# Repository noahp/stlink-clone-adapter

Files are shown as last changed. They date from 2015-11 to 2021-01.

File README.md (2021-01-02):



# stlink-clone-adapter <!-- omit in toc -->

- [Variants](#variants)
  - [Variant 1](#variant-1)
  - [Variant 2](#variant-2)
  - [Variant X](#variant-x)
- [PCB Renders](#pcb-renders)
  - [Variant-1](#variant-1-1)
  - [Variant-2](#variant-2-1)
- [Part list](#part-list)
- [pyocd](#pyocd)

Adapter board for a 2x5 0.1" (2.54mm) header to arm cortex 10-pin connector.

This is useful when connecting ST-Link v2 clones to a standard ARM 2x5 1.27mm
pitch header.

## Variants

I know of 2 variants of the ST-Link v2 clones, with different pinouts on the 2x5 0.1"
(2.54mm) header. Different adapter boards provided for each variant.

One way to distinguish the variants; when unplugged, check for continuity on pins 3+4 or 5+6.

- pins 3+4 shorted, **variant-1**
- pins 5+6 shorted, **variant-2**

### Variant 1

Older model I bought in ~2016.

From the pin 1 marker on the header on the ST-Link, pinout is as follows:

|Funtion|Pin|Pin|Function|
|---|---|---|---|
|RST*|1|2|SWDIO|
|GND*|3|4|GND|
|SWIM|5|6|SWCLK|
|3.3V|7|8|3.3V|
|5.0V|9|10|5.0V|

**Note that the labeling is incorrect for some pins on the etching on the case /
on the silkscreen on the board. My device had the pinout for **Variant-2** on
the etching and just incorrect on the silkscreen markings 🤷.*

### Variant 2

Newer model I bought in 2020.

From the pin 1 marker on the header on the ST-Link, pinout is as follows:

|Funtion|Pin|Pin|Function|
|---|---|---|---|
|RST|1|2|SWCLK|
|SWIW|3|4|SWDIO|
|GND|5|6|GND|
|3.3V|7|8|3.3V|
|5.0V|9|10|5.0V|

Labeling appears to be correct on these devices.

### Variant X

*UNTESTED DESIGN*

Support both pinouts with a 3x4 0.1" header to select between them.

Alternative approaches:

- digital selection (mux the 4 connectors), controlled somehow by the signals.
  this has the defect of additional propogation losses through the mux, and
  complexity in the control circuit
- provide 2 2x5 0.1" headers on the board (would be a funky looking board!). the
  connectors are somewhat expensive at $0.80 @ qty 1 but makes for a simpler
  design
- provide a single 6-pin strip (3.3v, GND, RST, SWDIO, SWCLK, SWO) and use 0.1"
  jumper connectors to wire it to the probe (kinda janky connection vs. single
  connector though).

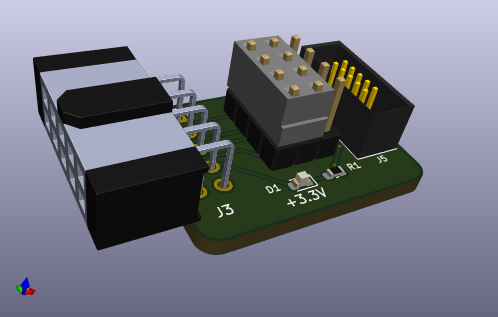
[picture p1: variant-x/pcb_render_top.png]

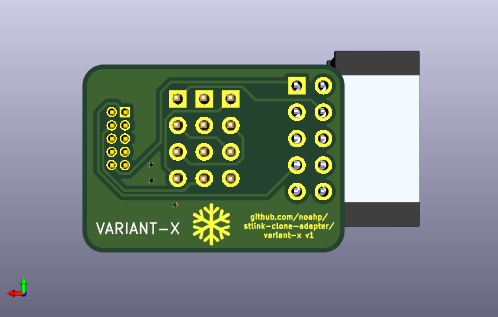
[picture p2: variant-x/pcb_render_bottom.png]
bottom


## PCB Renders

### Variant-1

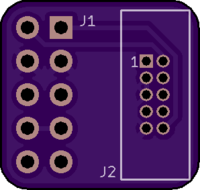
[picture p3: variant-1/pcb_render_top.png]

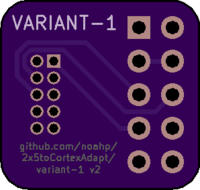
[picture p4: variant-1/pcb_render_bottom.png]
bottom


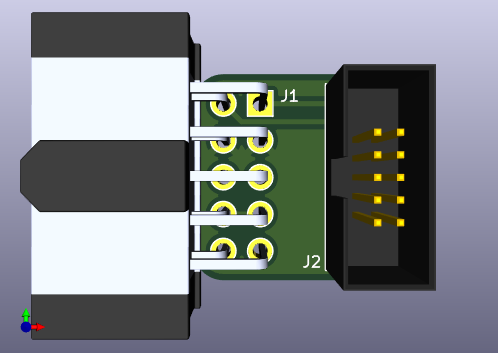
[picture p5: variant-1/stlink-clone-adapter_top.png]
3d-top

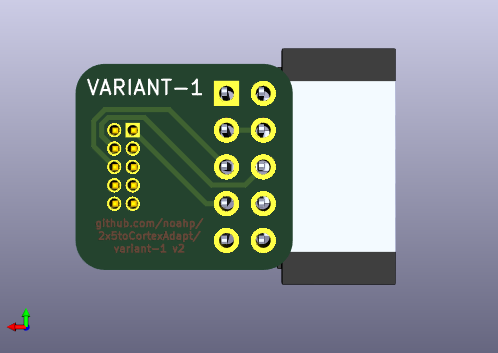
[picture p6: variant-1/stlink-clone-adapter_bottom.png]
3d-bottom


### Variant-2

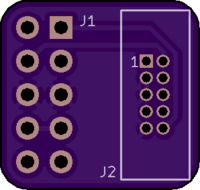
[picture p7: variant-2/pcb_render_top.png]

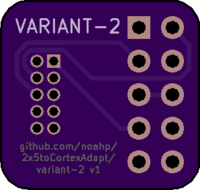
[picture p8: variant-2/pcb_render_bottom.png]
bottom


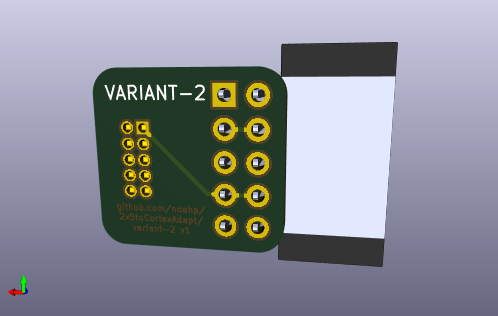
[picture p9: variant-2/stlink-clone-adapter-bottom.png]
3d


## Part list

- [2x5 header](http://www.digikey.com/product-search/en?keywords=SFH11-PBPC-D05-RA-BK)
- [arm 10 pin](http://www.digikey.com/product-detail/en/3220-10-0100-00/1175-1627-ND/3883661)
- [2x4 shunt/jumper](https://www.digikey.com/en/products/detail/amphenol-icc-fci/69145-208LF/1523748) [alternate](https://www.digikey.com/en/products/detail/samtec-inc/MNT-104-BK-G/6613574)

## pyocd

Quick note about using the stlink v2 clones with pyocd; I had the best luck
using the device after updating the firmware using the [official ST
updater](https://www.st.com/en/development-tools/stsw-link007.html):

```bash
❯ java -jar stsw-link007/AllPlatforms/STLinkUpgrade.jar -jtag_swim -force_prog
Firmware version detected: V2J29S7
................Upgrade is successful.
Version read: 2.37.7
```

After upating the version should report `V2J37S7` if you run the updater again.

There's a ton of information out there on the stlink devices themselves (I found
[this](https://hackaday.io/project/162597-st-link-clone-repurposing) helpful).

On ubuntu there's an available package
[stlink-tools](https://packages.ubuntu.com/search?keywords=stlink-tools)
([source](https://github.com/stlink-org/stlink)) which contains some utilities and udev rules for the st-link devices. I didn't end up using the tools themselves
but it could come in handy.

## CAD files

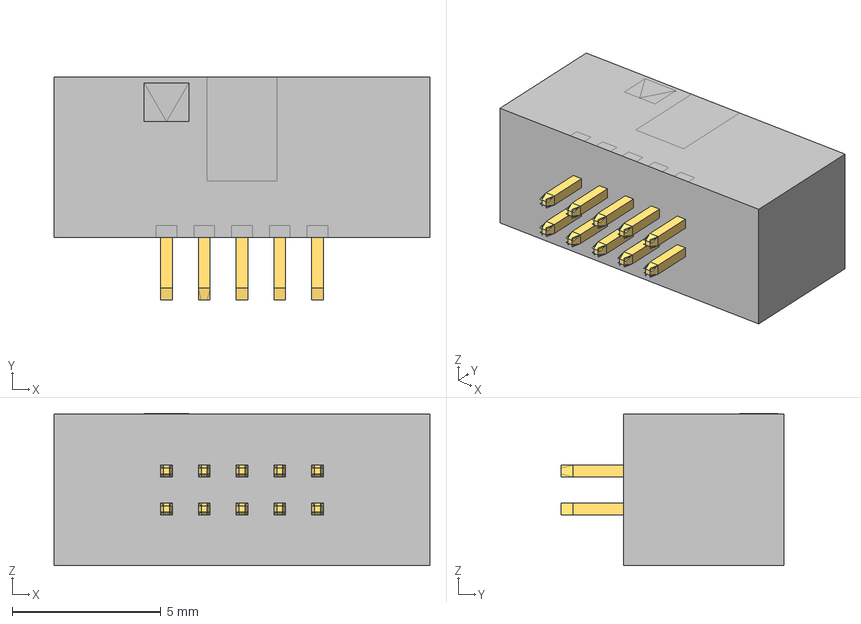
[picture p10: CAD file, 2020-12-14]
3220-10-0100.igs
12.7 x 7.50 x 5.13 mm

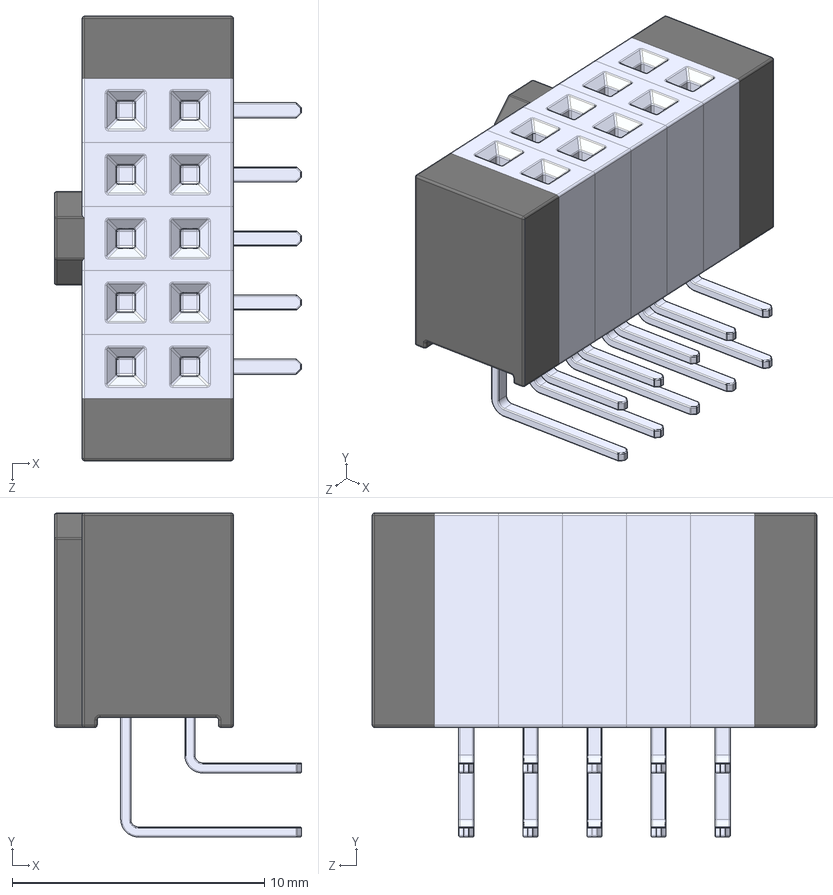
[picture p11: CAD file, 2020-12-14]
SFH11-xxPC-D05-RA-BK.IGS
9.80 x 12.8 x 17.6 mm

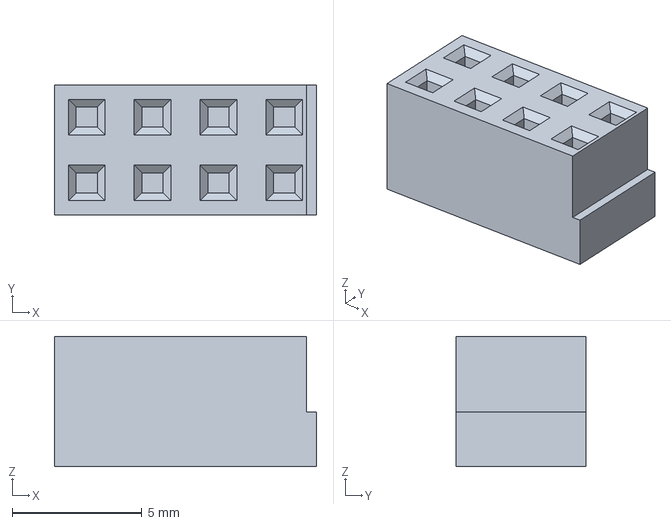
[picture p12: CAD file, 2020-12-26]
69145-x08.igs
10.1 x 5.03 x 5.03 mm

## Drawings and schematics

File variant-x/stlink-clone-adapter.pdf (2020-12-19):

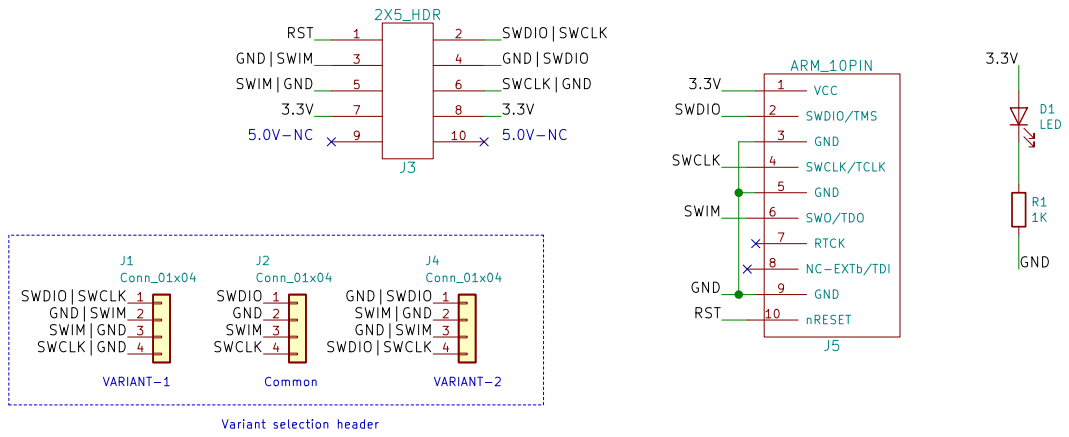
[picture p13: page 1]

File: stlink-clone-adapter.sch Sheet: /
Id: 1/1 Title:

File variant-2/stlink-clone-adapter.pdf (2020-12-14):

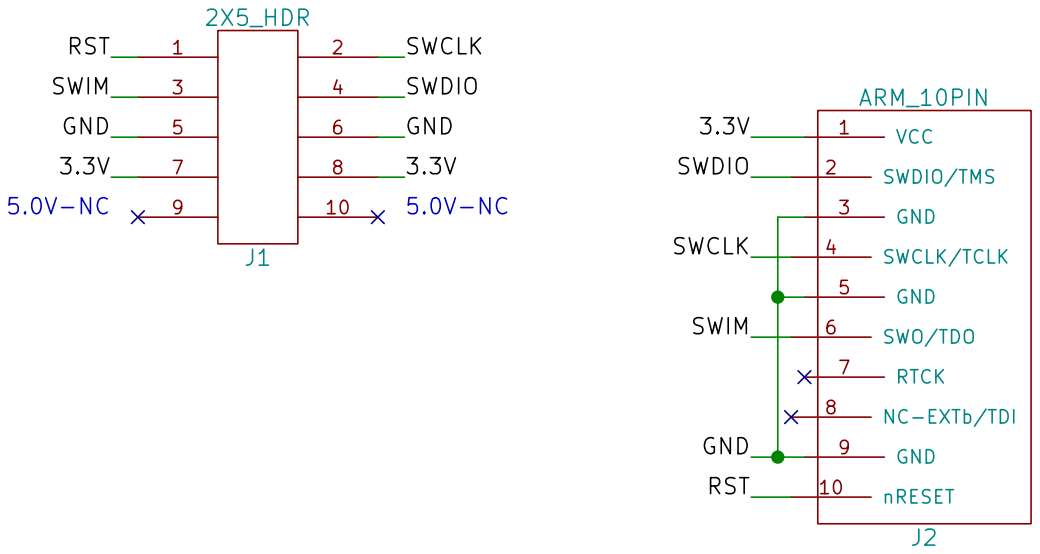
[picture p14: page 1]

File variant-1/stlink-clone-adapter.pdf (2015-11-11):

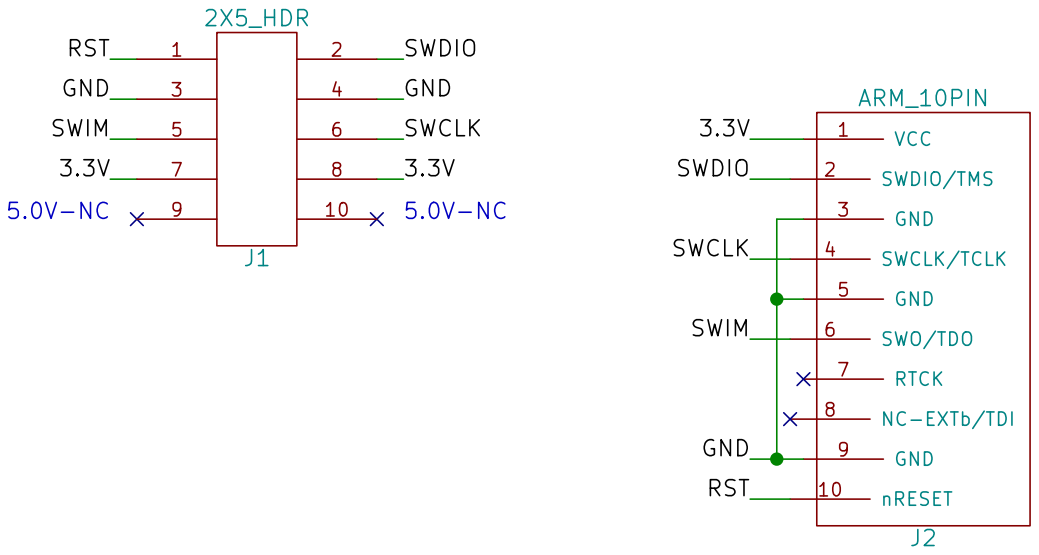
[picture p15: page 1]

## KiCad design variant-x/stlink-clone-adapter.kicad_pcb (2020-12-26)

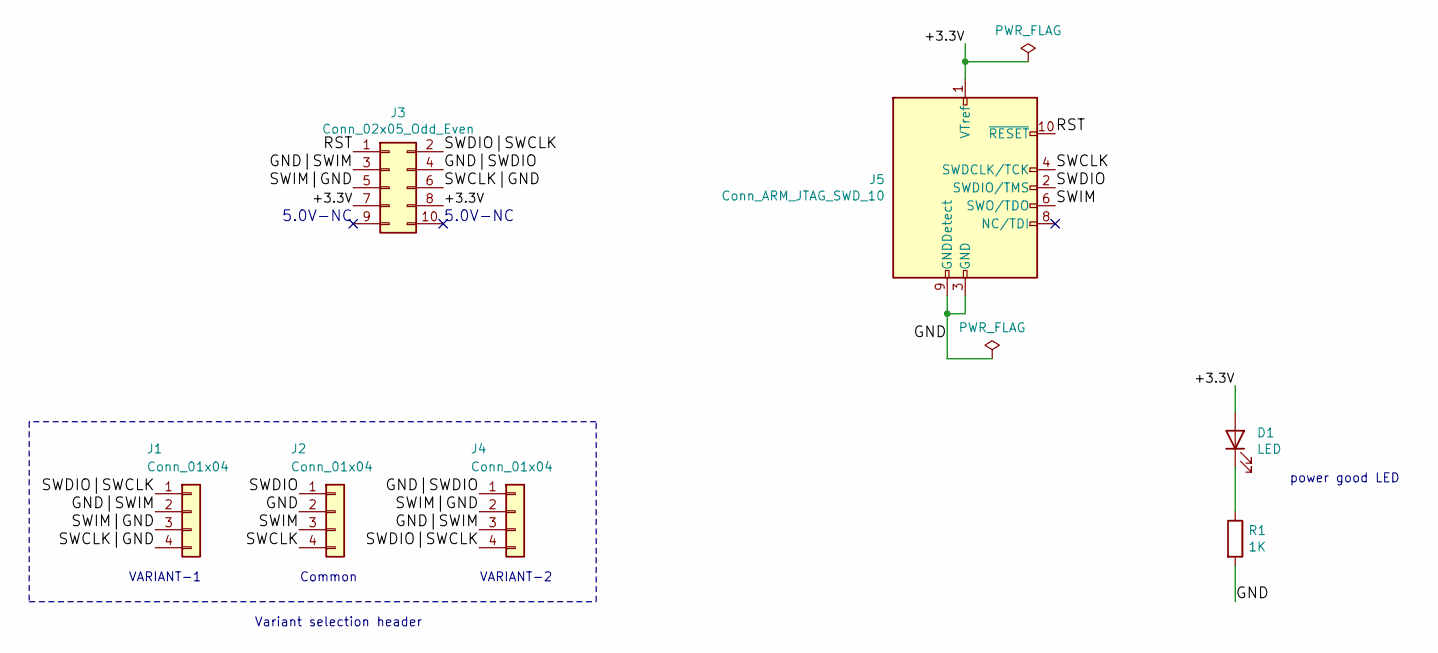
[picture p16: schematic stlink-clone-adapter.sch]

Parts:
D1: LED; LED_0603_1608Metric
J1, J2, J4: Conn_01x04; PinHeader_1x04_P2.54mm_Vertical
J3: Conn_02x05_Odd_Even; PinSocket_2x05_P2.54mm_Horizontal
J5: Conn_ARM_JTAG_SWD_10; ARM_10_PIN
R1: 1K; R_0603_1608Metric

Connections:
/+3.3V: D1.2 (A), J3.7, J3.8, J5.1 (VTref)
/GND: J2.2, J5.3 (GND), J5.5 (GND), J5.9 (GNDDetect), R1.2
/GND|SWDIO: J3.4, J4.1
/GND|SWIM: J1.2, J3.3, J4.3
/RST: J3.1, J5.10 (~RESET~)
/SWCLK: J2.4, J5.4 (SWDCLK/TCK)
/SWCLK|GND: J1.4, J3.6
/SWDIO: J2.1, J5.2 (SWDIO/TMS)
/SWDIO|SWCLK: J1.1, J3.2, J4.4
/SWIM: J2.3, J5.6 (SWO/TDO)
/SWIM|GND: J1.3, J3.5, J4.2
unnamed: D1.1 (K), R1.1

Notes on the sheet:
5.0V-NC
VARIANT-1
VARIANT-2
Variant selection header
Common
power good LED

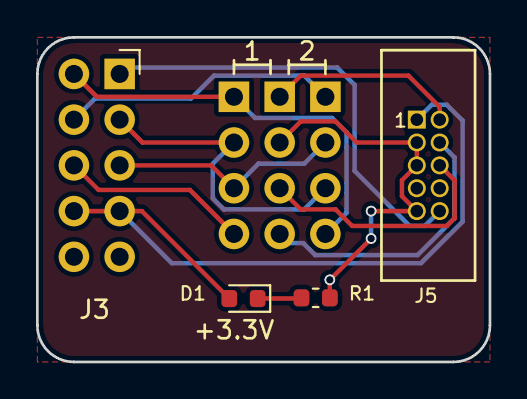
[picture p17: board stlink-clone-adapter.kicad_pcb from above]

Board: 2 copper layers, 25.1 x 18.0 mm, 7 parts (0 on the bottom side), 12 nets.

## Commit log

2015-11-11 layout done.
    [2x5toCortexAdapt-B_Cu.gbr, 2x5toCortexAdapt-B_Mask.gbr, 2x5toCortexAdapt-B_SilkS.gbr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]
2015-11-11 add pcb renders
2020-12-14 move to variant-1
    [2x5toCortexAdapt-B_Cu.gbr, 2x5toCortexAdapt-B_Mask.gbr, 2x5toCortexAdapt-B_SilkS.gbr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]
2020-12-14 update 3d render for variant-1
    [2x5toCortexAdapt.kicad_pcb, 2x5toCortexAdapt.sch, 3220-10-0100.igs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]
2020-12-14 variant-1 v2 update
    [2x5toCortexAdapt-B_Cu.gbr, 2x5toCortexAdapt-B_Mask.gbr, 2x5toCortexAdapt-B_SilkS.gbr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]
2020-12-19 move and rename to stlink-clone-adapter
    [2x5toCortexAdapt-B_Cu.gbr, 2x5toCortexAdapt-B_Mask.gbr, 2x5toCortexAdapt-B_SilkS.gbr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]
2020-12-19 variant-x plot done
    [stlink-clone-adapter.kicad_pcb, stlink-clone-adapter.sch]
2020-12-19 remove gerbers. oshpark doesn't need them
    [stlink-clone-adapter-B_Cu.gbr, stlink-clone-adapter-B_Mask.gbr, stlink-clone-adapter-B_SilkS.gbr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]
2020-12-19 note for jumper
    [stlink-clone-adapter.kicad_pcb]
2020-12-19 fix 2x5 header
    [stlink-clone-adapter.kicad_pcb, stlink-clone-adapter.sch]
2020-12-19 1K value for 3.3v status led
    [stlink-clone-adapter.sch]
2020-12-26 add example 2x4 jumper
    [69145-x08.igs, stlink-clone-adapter.kicad_pcb]
2021-01-03 pour bottom ground
    [stlink-clone-adapter.kicad_pcb]
